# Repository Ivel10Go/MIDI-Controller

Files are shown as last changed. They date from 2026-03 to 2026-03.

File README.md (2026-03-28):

# 🎹 MIDI Controller PCB
 
> A custom MIDI keyboard PCB built as part of the [Hackclub Blueprint](https://blueprint.hackclub.com/starter-projects/midi) program.
 


---
 
## Overview
 
This is a fully custom MIDI controller PCB featuring a mechanical switch matrix, per-key RGB lighting, rotary encoders, a high-quality audio DAC, and an ST7735R display — all driven by a Raspberry Pi Pico (Orpheus Pico).
 
<!-- Add more photos here — front/back of PCB, schematic screenshot, 3D render, etc. -->
<!-- ![Schematic](./images/schematic.png) -->
<!-- ![PCB Layout](./images/pcb_layout.png) -->




---
 
## Features
 
- **38 mechanical keys** in a switch matrix (with 1N4148 diodes for anti-ghosting)
- **38 SK6812MINI-E RGB LEDs** — per-key addressable RGB lighting
- **2 rotary encoders** (Alps EC11E) with clickable push switch
- **PCM5102A audio DAC** with 3.5mm stereo output via I²S
- **ST7735R 1.8" TFT display** via SPI
- **MCP23017 I²C GPIO expander** for the key matrix
- **Raspberry Pi Pico (Orpheus Pico)** as the main microcontroller
- USB powered (5V via Pico)
- M3 and M2.5 mounting holes for case attachment
 
---

##Case

 I decided to go with an open design because I really like the look of the PCB. Thanks to [Miraculix50](https://github.com/Miraculix50) for the help.
 


# BOM
Bill of Materials:

Qty. | Item
:-:|:-:
1 | Orpheus Pico
38 | Cherry MX Switch
38 | Keycaps
1 | ST7735R LCD
38 | 1N4148
37 | SK6812 MINI LEDs
2 | EC11 rotary encoders
1 | PCM5100 IIS DAC
1 | MCP23017 I/O Expander
1 | PJ-320A 3.5mm TRRS Audio Jack
2 | 4,7 kΩ
2 | 10 kΩ

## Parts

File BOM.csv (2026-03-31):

Qty | Teil | Link
1 | Raspberry Pi Pico / Orpheus Pico
38 | Cherry MX Switch | https://www.reichelt.de/de/de/shop/produkt/cherry_mx_red_rgb_-_tastenmodul-401645
2 | Rotary Encoder Alps EC11 | https://de.aliexpress.com/item/1005007644083514.html?mp=1
45 | SK6812MINI-E | https://de.aliexpress.com/item/1005005248164351.html
38 | 1N4148 | https://www.reichelt.de/de/de/shop/produkt/schalt-diode_100_v_150_ma_do-35-1730
1 | MCP23017-E/SO | https://www.reichelt.de/de/de/i-o-erweiterung-16bit-1-8-5v-seriell-i2c-so-28-mcp23017-e-so-p282743.html
1 | PCM5100APWR | https://www.aliexpress.com/item/1005001555424851.html
1 | ST7735R Display | https://de.aliexpress.com/w/wholesale-ST7735-1.8-TFT-display.html
1 | 3.5mm Audio Jack TRS | https://de.aliexpress.com/item/33029465106.html?mp=1
2 | Widerstand
2 | Widerstand
38 | Keycaps | https://de.aliexpress.com/item/1005007791365492.html?mp=1

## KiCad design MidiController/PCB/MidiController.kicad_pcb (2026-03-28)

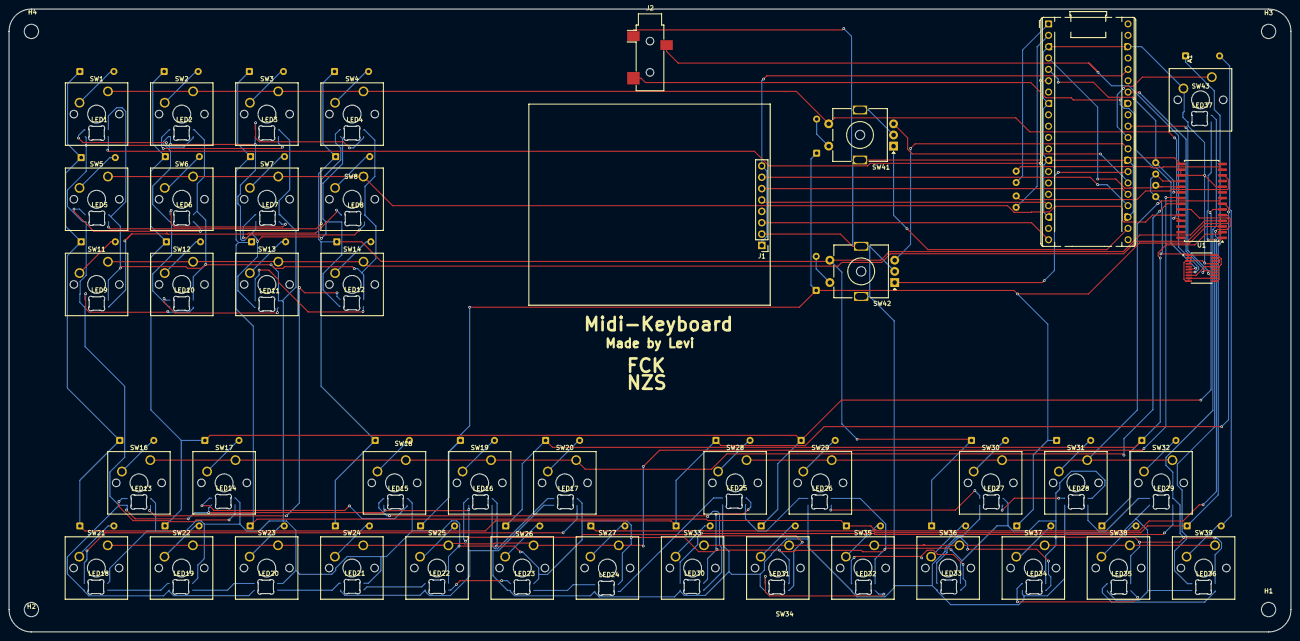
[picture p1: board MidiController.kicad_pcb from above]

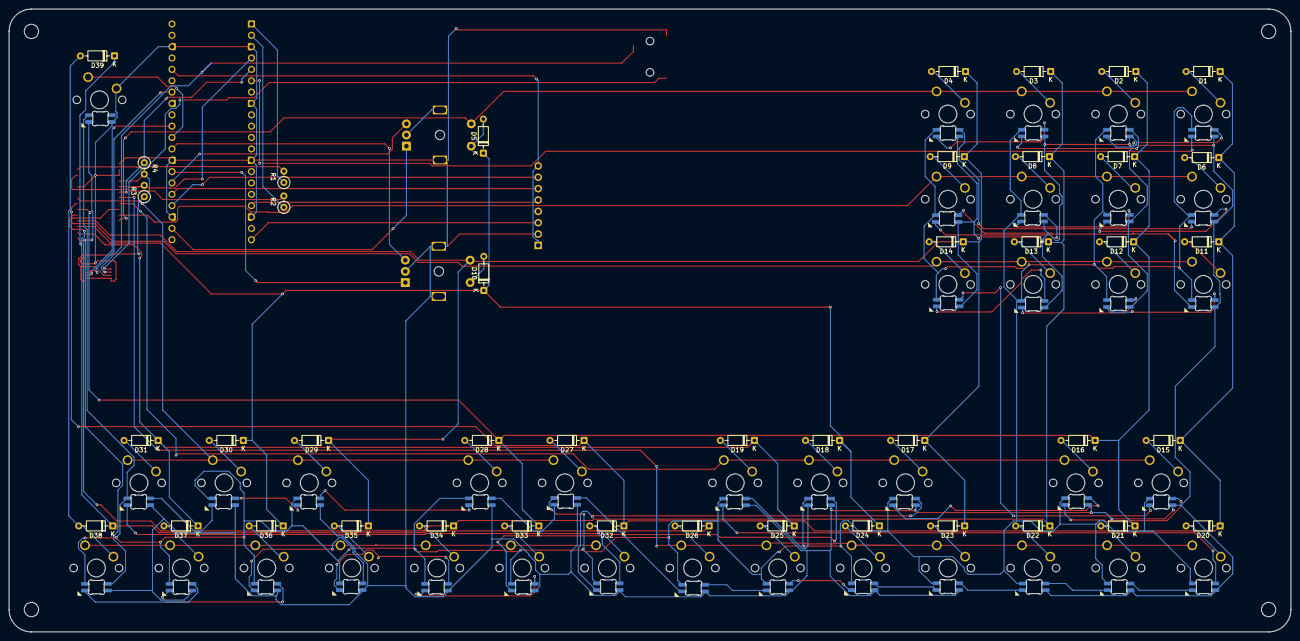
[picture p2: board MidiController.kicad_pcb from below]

Board: 2 copper layers, 286.7 x 139.3 mm, 128 parts (43 on the bottom side), 112 nets.

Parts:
A1: RaspberryPi_Pico; RaspberryPi_Pico_Common_THT
D1, D2, D3, D4, D5, D6, D7, D8, D9, D10, D11, D12, D13, D14, D15, D16, D17, D18, D19, D20, D21, D22, D23, D24, D25, D26, D27, D28, D29, D30, D31, D32, D33, D34, D35, D36, D37, D38, D39: 1N4148; D_DO-35_SOD27_P7.62mm_Horizontal
H1, H2, H3, H4: MountingHole; MountingHole_3.2mm_M3
J1: ST7735R; PinHeader_1x08_P2.54mm_Vertical
J2: AudioJack3; Jack_3.5mm_CUI_SJ-3523-SMT_Horizontal
LED1, LED2, LED3, LED4, LED5, LED6, LED7, LED8, LED9, LED10, LED11, LED12, LED13, LED14, LED15, LED16, LED17, LED18, LED19, LED20, LED21, LED22, LED23, LED24, LED25, LED26, LED27, LED28, LED29, LED30, LED31, LED32, LED33, LED34, LED35, LED36, LED37: SK6812MINI; SK6812MINI-E_fixed
R1, R2: 4.7k; R_Axial_DIN0207_L6.3mm_D2.5mm_P2.54mm_Vertical
R3, R4: 10k; R_Axial_DIN0207_L6.3mm_D2.5mm_P2.54mm_Vertical
SW1, SW2, SW3, SW4, SW5, SW6, SW7, SW8, SW11, SW12, SW13, SW14, SW16, SW17, SW18, SW19, SW20, SW21, SW22, SW23, SW24, SW25, SW26, SW27, SW28, SW29, SW30, SW31, SW32, SW33, SW34, SW35, SW36, SW37, SW38, SW39, SW43: SW_Push_45deg; SW_Cherry_MX_1.00u_PCB
SW41, SW42: RotaryEncoder_Switch_MP; RotaryEncoder_Alps_EC11E-Switch_Vertical_H20mm_MountingHoles
U1: MCP23017_SO; SOIC-28W_7.5x17.9mm_P1.27mm
U2: PCM5100; TSSOP-20_4.4x6.5mm_P0.65mm

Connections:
1A: A1.22 (GPIO17), SW41.A
1B: A1.26 (GPIO20), SW41.B
1S1: SW1.1, SW2.1, SW3.1, SW4.1, SW41.S1, U1.25 (GPA4)
1S2: D5.2 (A), SW41.S2
2A: A1.27 (GPIO21), SW42.A
2B: A1.29 (GPIO22), SW42.B
2S1: D4.1 (K), D9.1 (K), D14.1 (K), D17.1 (K), D23.1 (K), D29.1 (K), D35.1 (K), SW42.S1, U1.4 (GPB3)
2S2: D10.2 (A), SW42.S2
+3.3V: A1.36 (3V3), J1.1, J1.8
+3V3: R3.1, R4.2, U1.18 (~RESET), U2.1 (CPVDD), U2.8 (AVDD), U2.11 (FLT), U2.16 (FMT), U2.20 (DVDD)
+5V: LED1.4 (VDD), LED2.4 (VDD), LED3.4 (VDD), LED4.4 (VDD), LED5.4 (VDD), LED6.4 (VDD), LED7.4 (VDD), LED8.4 (VDD), LED9.4 (VDD), LED10.4 (VDD), LED11.4 (VDD), LED12.4 (VDD), LED13.4 (VDD), LED14.4 (VDD), LED15.4 (VDD), LED16.4 (VDD), LED17.4 (VDD), LED18.4 (VDD), LED19.4 (VDD), LED20.4 (VDD), LED21.4 (VDD), LED22.4 (VDD), LED23.4 (VDD), LED24.4 (VDD), LED25.4 (VDD), LED26.4 (VDD), LED27.4 (VDD), LED28.4 (VDD), LED29.4 (VDD), LED30.4 (VDD), LED31.4 (VDD), LED32.4 (VDD), LED33.4 (VDD), LED34.4 (VDD), LED35.4 (VDD), LED36.4 (VDD), LED37.4 (VDD)
A0: A1.17 (GPIO13), J1.5
BLCK: A1.31 (GPIO26_ADC0), U2.13 (BCK)
COL0: D1.1 (K), D6.1 (K), D11.1 (K), D15.1 (K), D20.1 (K), D27.1 (K), D32.1 (K), U1.7 (GPB6)
COL1: D2.1 (K), D7.1 (K), D12.1 (K), D16.1 (K), D21.1 (K), D28.1 (K), D33.1 (K), U1.6 (GPB5)
COL2: D3.1 (K), D8.1 (K), D13.1 (K), D22.1 (K), D34.1 (K), U1.5 (GPB4)
COL4: D5.1 (K), D10.1 (K), D18.1 (K), D24.1 (K), D30.1 (K), D36.1 (K), U1.3 (GPB2)
COL5: D19.1 (K), D25.1 (K), D31.1 (K), D37.1 (K), U1.2 (GPB1)
COL6: D26.1 (K), D38.1 (K), D39.1 (K), U1.1 (GPB0)
CS_LCD: A1.20 (GPIO15), J1.3
DIN: A1.34 (GPIO28_ADC2), U2.14 (DIN)
GND: A1.3 (GND), A1.8 (GND), A1.13 (GND), A1.18 (GND), A1.23 (GND), A1.28 (GND), A1.38 (GND), J1.2, J2.S, LED1.2 (VSS), LED2.2 (VSS), LED3.2 (VSS), LED4.2 (VSS), LED5.2 (VSS), LED6.2 (VSS), LED7.2 (VSS), LED8.2 (VSS), LED9.2 (VSS), LED10.2 (VSS), LED11.2 (VSS), LED12.2 (VSS), LED13.2 (VSS), LED14.2 (VSS), LED15.2 (VSS), LED16.2 (VSS), LED17.2 (VSS), LED18.2 (VSS), LED19.2 (VSS), LED20.2 (VSS), LED21.2 (VSS), LED22.2 (VSS), LED23.2 (VSS), LED24.2 (VSS), LED25.2 (VSS), LED26.2 (VSS), LED27.2 (VSS), LED28.2 (VSS), LED29.2 (VSS), LED30.2 (VSS), LED31.2 (VSS), LED32.2 (VSS), LED33.2 (VSS), LED34.2 (VSS), LED35.2 (VSS), LED36.2 (VSS), LED37.2 (VSS), SW41.C, SW41.MP, SW42.C, SW42.MP, SW43.2, U1.10 (VSS), U1.15 (A0), U1.16 (A1), U1.17 (A2), U2.3 (CPGND), U2.9 (AGND), U2.10 (DEMP), U2.12 (SCK), U2.17 (XSMT), U2.19 (DGND)
GPIOSCL: A1.2 (GPIO1), R2.1
GPIOSDA: A1.1 (GPIO0), R1.1
INTA: A1.4 (GPIO2), R3.2, U1.19 (INTB)
INTB: A1.5 (GPIO3), R4.1, U1.20 (INTA)
LED_DATA: A1.6 (GPIO4), LED1.3 (DIN)
MOSI: A1.25 (GPIO19), J1.6
unnamed: A1.30 (RUN), SW43.1
unnamed: D1.2 (A), SW1.2
unnamed: D2.2 (A), SW2.2
unnamed: D3.2 (A), SW3.2
unnamed: D4.2 (A), SW4.2
unnamed: D6.2 (A), SW5.2
unnamed: D7.2 (A), SW6.2
unnamed: D8.2 (A), SW7.2
unnamed: D9.2 (A), SW8.2
unnamed: D11.2 (A), SW11.2
unnamed: D12.2 (A), SW12.2
unnamed: D13.2 (A), SW13.2
unnamed: D14.2 (A), SW14.2
unnamed: D15.2 (A), SW16.2
unnamed: D16.2 (A), SW17.2
unnamed: D17.2 (A), SW18.2
unnamed: D18.2 (A), SW19.2
unnamed: D19.2 (A), SW20.2
unnamed: D20.2 (A), SW21.2
unnamed: D21.2 (A), SW22.2
unnamed: D22.2 (A), SW23.2
unnamed: D23.2 (A), SW24.2
unnamed: D24.2 (A), SW25.2
unnamed: D25.2 (A), SW26.2
unnamed: D26.2 (A), SW27.2
unnamed: D27.2 (A), SW28.2
unnamed: D28.2 (A), SW29.2
unnamed: D29.2 (A), SW30.2
unnamed: D30.2 (A), SW31.2
unnamed: D31.2 (A), SW32.2
unnamed: D32.2 (A), SW33.2
unnamed: D33.2 (A), SW34.2
unnamed: D34.2 (A), SW35.2
unnamed: D35.2 (A), SW36.2
unnamed: D36.2 (A), SW37.2
unnamed: D37.2 (A), SW38.2
unnamed: D38.2 (A), D39.2 (A), SW39.2
unnamed: LED1.1 (DOUT), LED2.3 (DIN)
unnamed: LED2.1 (DOUT), LED3.3 (DIN)
unnamed: LED3.1 (DOUT), LED4.3 (DIN)
unnamed: LED4.1 (DOUT), LED5.3 (DIN)
unnamed: LED5.1 (DOUT), LED6.3 (DIN)
unnamed: LED6.1 (DOUT), LED7.3 (DIN)
unnamed: LED7.1 (DOUT), LED8.3 (DIN)
unnamed: LED8.1 (DOUT), LED9.3 (DIN)
unnamed: LED9.1 (DOUT), LED10.3 (DIN)
unnamed: LED10.1 (DOUT), LED11.3 (DIN)
unnamed: LED11.1 (DOUT), LED12.3 (DIN)
unnamed: LED12.1 (DOUT), LED13.3 (DIN)
unnamed: LED13.1 (DOUT), LED14.3 (DIN)
unnamed: LED14.1 (DOUT), LED15.3 (DIN)
unnamed: LED15.1 (DOUT), LED30.3 (DIN)
unnamed: LED16.3 (DIN), LED17.1 (DOUT)
unnamed: LED16.1 (DOUT), LED31.3 (DIN)
unnamed: LED17.3 (DIN), LED18.1 (DOUT)
unnamed: LED18.3 (DIN), LED19.1 (DOUT)
unnamed: LED19.3 (DIN), LED20.1 (DOUT)
unnamed: LED20.3 (DIN), LED21.1 (DOUT)
unnamed: LED21.3 (DIN), LED22.1 (DOUT)
unnamed: LED22.3 (DIN), LED23.1 (DOUT)
unnamed: LED23.3 (DIN), LED24.1 (DOUT)
unnamed: LED24.3 (DIN), LED25.1 (DOUT)
unnamed: LED25.3 (DIN), LED26.1 (DOUT)
unnamed: LED26.3 (DIN), LED27.1 (DOUT)
unnamed: LED27.3 (DIN), LED28.1 (DOUT)
unnamed: LED28.3 (DIN), LED29.1 (DOUT)
unnamed: LED29.3 (DIN), LED30.1 (DOUT)
unnamed: LED31.1 (DOUT), LED32.3 (DIN)
unnamed: LED32.1 (DOUT), LED33.3 (DIN)
unnamed: LED33.1 (DOUT), LED34.3 (DIN)
unnamed: LED34.1 (DOUT), LED35.3 (DIN)
unnamed: LED35.1 (DOUT), LED36.3 (DIN)
unnamed: LED36.1 (DOUT), LED37.3 (DIN)
unnamed: R2.2, U1.12 (SCK)
unnamed: R1.2, U1.13 (SDA)
OUTLEFT: J2.T, U2.6 (OUTL)
OUTRIGHT: J2.R, U2.7 (OUTR)
ROW1: SW5.1, SW6.1, SW7.1, SW8.1, U1.24 (GPA3)
ROW2: SW11.1, SW12.1, SW13.1, SW14.1, U1.23 (GPA2)
ROW3: SW16.1, SW17.1, SW18.1, SW19.1, SW20.1, U1.22 (GPA1)
ROW4: SW21.1, SW22.1, SW23.1, SW24.1, SW25.1, SW26.1, SW27.1, U1.21 (GPA0)
ROW5: SW28.1, SW29.1, SW30.1, SW31.1, SW32.1, U1.8 (GPB7)
ROW6: SW33.1, SW34.1, SW35.1, SW36.1, SW37.1, SW38.1, SW39.1
SCK: A1.24 (GPIO18), J1.7

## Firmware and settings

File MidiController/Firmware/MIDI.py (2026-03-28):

# MIDI Controller Keyboard - CircuitPython
# Raspberry Pi Pico 2 + MCP23017 key matrix + ST7735 display + rotary encoders

import board
import busio
import digitalio
import time
import displayio
from fourwire import FourWire
from adafruit_st7735r import ST7735R
import adafruit_midi
from adafruit_midi.note_off import NoteOff
from adafruit_midi.note_on import NoteOn
from adafruit_midi.pitch_bend import PitchBend
from adafruit_midi.control_change import ControlChange
from adafruit_mcp230xx.mcp23017 import MCP23017
import rotaryio
import usb_midi

# ============ PIN ASSIGNMENTS (from KiCad schematic) ============
# I2C: GPIO0=SDA, GPIO1=SCL (MCP23017)
# SPI Display: GPIO18=SCK, GPIO19=MOSI, GPIO15=CS_LCD, GPIO13=A0/DC, GPIO8=RST
# Encoder 1: GPIO17=1A, GPIO20=1B
# Encoder 2: GPIO21=2A, GPIO22=2B
# I2S DAC: GPIO26=BLCK, GPIO27=LRCLK, GPIO28=DIN (optional - for future audio)

# ============ KEY MATRIX (MCP23017) ============
# Rows: GPA0, GPA1, GPA2, GPA3, GPA4, GPB7 (6 rows)
# Cols: GPB0, GPB1, GPB2, GPB3, GPB4, GPB5, GPB6 (7 cols)
# 6x7 = 42 keys | Rows 0-2: User buttons/encoders | Rows 3-6: Piano keys (low + high octave)

ROWS = 6
COLS = 7
NUM_KEYS = ROWS * COLS

# Base MIDI note (C2 = 36). Keys map to 36-77 (C2 to F5)
BASE_NOTE = 36
VELOCITY = 127

# Octave shift (0 = no shift, 12 = +1 octave, -12 = -1 octave)
octave_shift = 0

# ============ INITIALIZE I2C & MCP23017 ============
i2c = busio.I2C(board.GP0, board.GP1)
mcp = MCP23017(i2c)

# Create row pins (outputs) - GPA0-4, GPB7
row_pins = [
    mcp.get_pin(0),   # GPA0
    mcp.get_pin(1),   # GPA1
    mcp.get_pin(2),   # GPA2
    mcp.get_pin(3),   # GPA3
    mcp.get_pin(4),   # GPA4
    mcp.get_pin(15),  # GPB7
]
# Create column pins (inputs with pull-up) - GPB0-6
col_pins = [
    mcp.get_pin(8),   # GPB0
    mcp.get_pin(9),   # GPB1
    mcp.get_pin(10),  # GPB2
    mcp.get_pin(11),  # GPB3
    mcp.get_pin(12),  # GPB4
    mcp.get_pin(13),  # GPB5
    mcp.get_pin(14),  # GPB6
]

# Configure pins
for pin in row_pins:
    pin.switch_to_output(value=True)  # High = inactive
for pin in col_pins:
    pin.switch_to_input(pull=digitalio.Pull.UP)

# ============ KEY STATE (for debouncing) ============
key_state = [False] * NUM_KEYS

def scan_matrix():
    """Scan key matrix and return list of (key_number, pressed)."""
    events = []
    for row in range(ROWS):
        # Drive current row low
        row_pins[row].value = False
        time.sleep(0.001)  # Settling time
        # Read columns
        for col in range(COLS):
            key_num = row * COLS + col
            pressed = not col_pins[col].value  # Low = pressed (pull-up)
            if pressed != key_state[key_num]:
                key_state[key_num] = pressed
                events.append((key_num, pressed))
        # Drive row high again
        row_pins[row].value = True
    return events

# ============ ROTARY ENCODERS ============
encoder1 = rotaryio.IncrementalEncoder(board.GP17, board.GP20)
encoder2 = rotaryio.IncrementalEncoder(board.GP21, board.GP22)
enc1_pos = encoder1.position
enc2_pos = encoder2.position

# ============ DISPLAY ============
displayio.release_displays()
spi = busio.SPI(board.GP18, MOSI=board.GP19)
display_bus = FourWire(
    spi,
    command=board.GP13,
    chip_select=board.GP15,
    reset=board.GP8,
)
display = ST7735R(display_bus, width=128, height=160, rotation=270)

# Create main group and show
main_group = displayio.Group()
display.show(main_group)

# Simple splash text
text_area = None
try:
    from adafruit_display_text import label
    import terminalio
    text_area = label.Label(terminalio.FONT, text="MIDI Keyboard", color=0x00FF00)
    text_area.x = 10
    text_area.y = 70
    main_group.append(text_area)
except (ImportError, OSError):
    pass

# ============ MIDI ============
midi = adafruit_midi.MIDI(
    midi_in=usb_midi.ports[0],
    in_channel=0,
    midi_out=usb_midi.ports[1],
    out_channel=0,
)

# ============ MAIN LOOP ============
last_display_update = 0
pitch_bend_center = 8192  # 14-bit center
current_pitch_bend = pitch_bend_center

while True:
    # Scan keyboard matrix
    for key_num, pressed in scan_matrix():
        # Rows 0-2: control buttons (octave up/down, etc.)
        if key_num < 3 * COLS:  # First 3 rows = user buttons
            if pressed and key_num == 0:  # Octave down
                octave_shift = max(-24, octave_shift - 12)
            elif pressed and key_num == 1:  # Octave up
                octave_shift = min(24, octave_shift + 12)
            # Add more control mappings as needed
        else:
            # Rows 3-5: piano keys (low + high octave) - send MIDI
            midi_note = BASE_NOTE + (key_num - 3 * COLS) + octave_shift
            midi_note = max(0, min(127, midi_note))
            if pressed:
                midi.send(NoteOn(midi_note, VELOCITY))
            else:
                midi.send(NoteOff(midi_note, 0))

    # Encoder 1 = Pitch bend
    pos1 = encoder1.position
    if pos1 != enc1_pos:
        delta = pos1 - enc1_pos
        current_pitch_bend = max(0, min(16383, current_pitch_bend + delta * 400))
        midi.send(PitchBend(current_pitch_bend))
        enc1_pos = pos1

    # Encoder 2 = Modulation wheel (CC 1)
    pos2 = encoder2.position
    if pos2 != enc2_pos:
        delta = pos2 - enc2_pos
        mod_value = max(0, min(127, 64 + delta * 10))
        midi.send(ControlChange(1, mod_value))
        enc2_pos = pos2

    # Return pitch bend to center when encoder not moved (optional)
    # current_pitch_bend = pitch_bend_center  # Uncomment for spring-back

    # Update display periodically
    now = time.monotonic()
    if text_area and (now - last_display_update) > 0.5:
        text_area.text = f"Oct:{octave_shift//12:+d}"
        last_display_update = now

    time.sleep(0.01)  # ~100Hz scan rate

    #test

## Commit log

2026-03-28 Add BOM section to README
    Added a Bill of Materials section with itemized components.
2026-03-28 Revise README for MIDI Controller project
    Updated project title and added detailed overview and features of the MIDI controller PCB.
2026-03-28 Remove 1 µF capacitor from the list
2026-03-28 Add case design section to README
    Added a section about the case design with images.
2026-03-29 Add case .step file
2026-03-31 Add BOM.csv with component details and links
    [BOM.csv]
